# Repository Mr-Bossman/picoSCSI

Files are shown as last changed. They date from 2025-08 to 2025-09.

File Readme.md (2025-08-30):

# PicoSCSI

## A SD sard to Parallel SCSI hard drive emulator

### Board

The board design is lossely based on the [BlueSCSI V1](https://github.com/erichelgeson/BlueSCSI) and the [ZuluSCSI Pico](https://github.com/ZuluSCSI/ZuluSCSI-Pico-OSHW).
The [RP2350](https://www.raspberrypi.com/products/rp2350/) the MCU on the [Raspberry PI Pico 2](https://www.raspberrypi.com/products/raspberry-pi-pico-2/) is [5V tollerant](https://www.raspberrypi.com/news/rp2350-a4-rp2354-and-a-new-hacking-challenge/) meaning no level translation logic is nessasary.
Like BlueSCSI this outputs 3.3V to the bus, which is compliant with LV SCSI.

#### Documents relating to 5V tollerance
[Piers Finlayson's video](https://www.youtube.com/watch?v=Zy8IMe6fMI4&t=1768s) on the RP2350 variant of
[one-rom](https://github.com/piersfinlayson/one-rom/blob/main/sdrr-pcb/verified/rp2350-24-pin-rev-a/one-rom-24-pin-rp2350-rev-a-schematic.pdf) talks about caveats this may have.
The A4 silicon revision adds support for this https://www.raspberrypi.com/news/rp2350-a4-rp2354-and-a-new-hacking-challenge noted at the bottom.

### Firmware

Coming soon will be based on [ZuluSCSI firmware](https://github.com/ZuluSCSI/ZuluSCSI-firmware)

### TODO:

Add both SMD and THT versions
Add DB25 version
Fix Pi Pico not having combined THT and SMD footprint

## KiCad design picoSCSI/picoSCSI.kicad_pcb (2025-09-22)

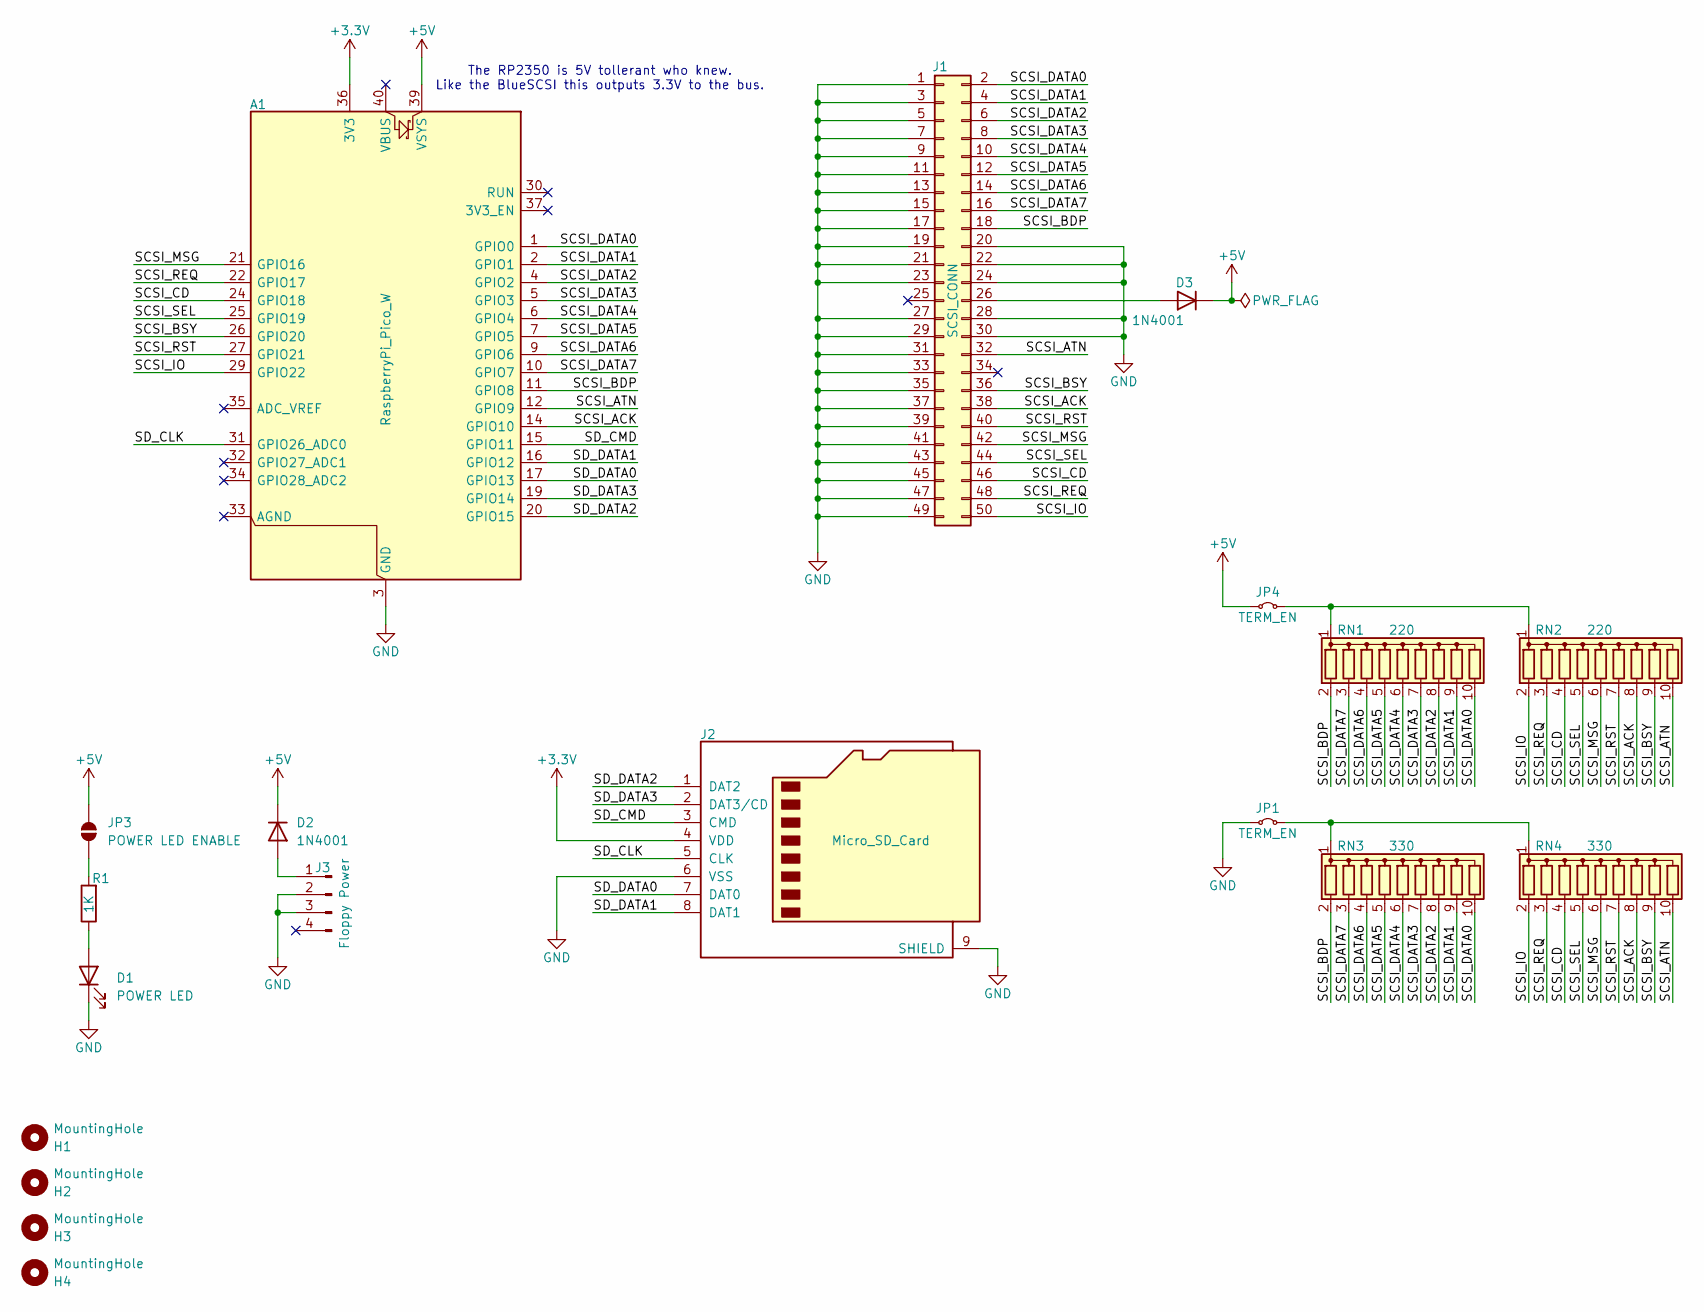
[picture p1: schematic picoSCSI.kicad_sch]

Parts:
A1: RaspberryPi_Pico_W; RaspberryPi_Pico_W_SMD_HandSolder
D1: POWER LED; LED_D5.0mm
D2, D3: 1N4001; D_DO-41_SOD81_P7.62mm_Horizontal
H1, H2, H3, H4: MountingHole; MountingHole_3.2mm_M3_ISO7380
J1: SCSI_CONN; IDC-Header_2x25_P2.54mm_Vertical
J2: Micro_SD_Card; microSD_HC_Wuerth_693072010801
J3: Floppy Power; JST_PH_B4B-PH-K_1x04_P2.00mm_Vertical
JP1, JP4: TERM_EN; PinSocket_1x02_P2.54mm_Vertical
JP3: POWER LED ENABLE; SolderJumper-2_P1.3mm_Open_RoundedPad1.0x1.5mm
R1: 1K; R_Axial_DIN0204_L3.6mm_D1.6mm_P5.08mm_Horizontal
RN1, RN2: 220; R_Array_SIP10
RN3, RN4: 330; R_Array_SIP10

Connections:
+3.3V: A1.36 (3V3), J2.4 (VDD)
+5V: A1.39 (VSYS), D2.1 (K), D3.1 (K), JP3.2 (B), JP4.1 (A)
/SCSI_ACK: A1.14 (GPIO10), J1.38, RN2.8 (R7), RN4.8 (R7)
/SCSI_ATN: A1.12 (GPIO9), J1.32, RN2.10 (R9), RN4.10 (R9)
/SCSI_BDP: A1.11 (GPIO8), J1.18, RN1.2 (R1), RN3.2 (R1)
/SCSI_BSY: A1.26 (GPIO20), J1.36, RN2.9 (R8), RN4.9 (R8)
/SCSI_CD: A1.24 (GPIO18), J1.46, RN2.4 (R3), RN4.4 (R3)
/SCSI_DATA0: A1.1 (GPIO0), J1.2, RN1.10 (R9), RN3.10 (R9)
/SCSI_DATA1: A1.2 (GPIO1), J1.4, RN1.9 (R8), RN3.9 (R8)
/SCSI_DATA2: A1.4 (GPIO2), J1.6, RN1.8 (R7), RN3.8 (R7)
/SCSI_DATA3: A1.5 (GPIO3), J1.8, RN1.7 (R6), RN3.7 (R6)
/SCSI_DATA4: A1.6 (GPIO4), J1.10, RN1.6 (R5), RN3.6 (R5)
/SCSI_DATA5: A1.7 (GPIO5), J1.12, RN1.5 (R4), RN3.5 (R4)
/SCSI_DATA6: A1.9 (GPIO6), J1.14, RN1.4 (R3), RN3.4 (R3)
/SCSI_DATA7: A1.10 (GPIO7), J1.16, RN1.3 (R2), RN3.3 (R2)
/SCSI_IO: A1.29 (GPIO22), J1.50, RN2.2 (R1), RN4.2 (R1)
/SCSI_MSG: A1.21 (GPIO16), J1.42, RN2.6 (R5), RN4.6 (R5)
/SCSI_REQ: A1.22 (GPIO17), J1.48, RN2.3 (R2), RN4.3 (R2)
/SCSI_RST: A1.27 (GPIO21), J1.40, RN2.7 (R6), RN4.7 (R6)
/SCSI_SEL: A1.25 (GPIO19), J1.44, RN2.5 (R4), RN4.5 (R4)
/SD_CLK: A1.31 (GPIO26_ADC0), J2.5 (CLK)
/SD_CMD: A1.15 (GPIO11), J2.3 (CMD)
/SD_DATA0: A1.17 (GPIO13), J2.7 (DAT0)
/SD_DATA1: A1.16 (GPIO12), J2.8 (DAT1)
/SD_DATA2: A1.20 (GPIO15), J2.1 (DAT2)
/SD_DATA3: A1.19 (GPIO14), J2.2 (DAT3/CD)
GND: A1.3 (GND), A1.8 (GND), A1.13 (GND), A1.18 (GND), A1.23 (GND), A1.28 (GND), A1.38 (GND), D1.1 (K), J1.1, J1.3, J1.5, J1.7, J1.9, J1.11, J1.13, J1.15, J1.17, J1.19, J1.20, J1.21, J1.22, J1.23, J1.24, J1.27, J1.28, J1.29, J1.30, J1.31, J1.33, J1.35, J1.37, J1.39, J1.41, J1.43, J1.45, J1.47, J1.49, J2.6 (VSS), J2.9 (SHIELD), J3.2, J3.3, JP1.1 (A)
unnamed: D1.2 (A), R1.1
unnamed: D2.2 (A), J3.1
unnamed: D3.2 (A), J1.26
unnamed: JP1.2 (B), RN3.1 (common), RN4.1 (common)
unnamed: JP3.1 (A), R1.2
unnamed: JP4.2 (B), RN1.1 (common), RN2.1 (common)

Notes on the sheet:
The RP2350 is 5V tollerant who knew. Like the BlueSCSI this outputs 3.3V to the bus.

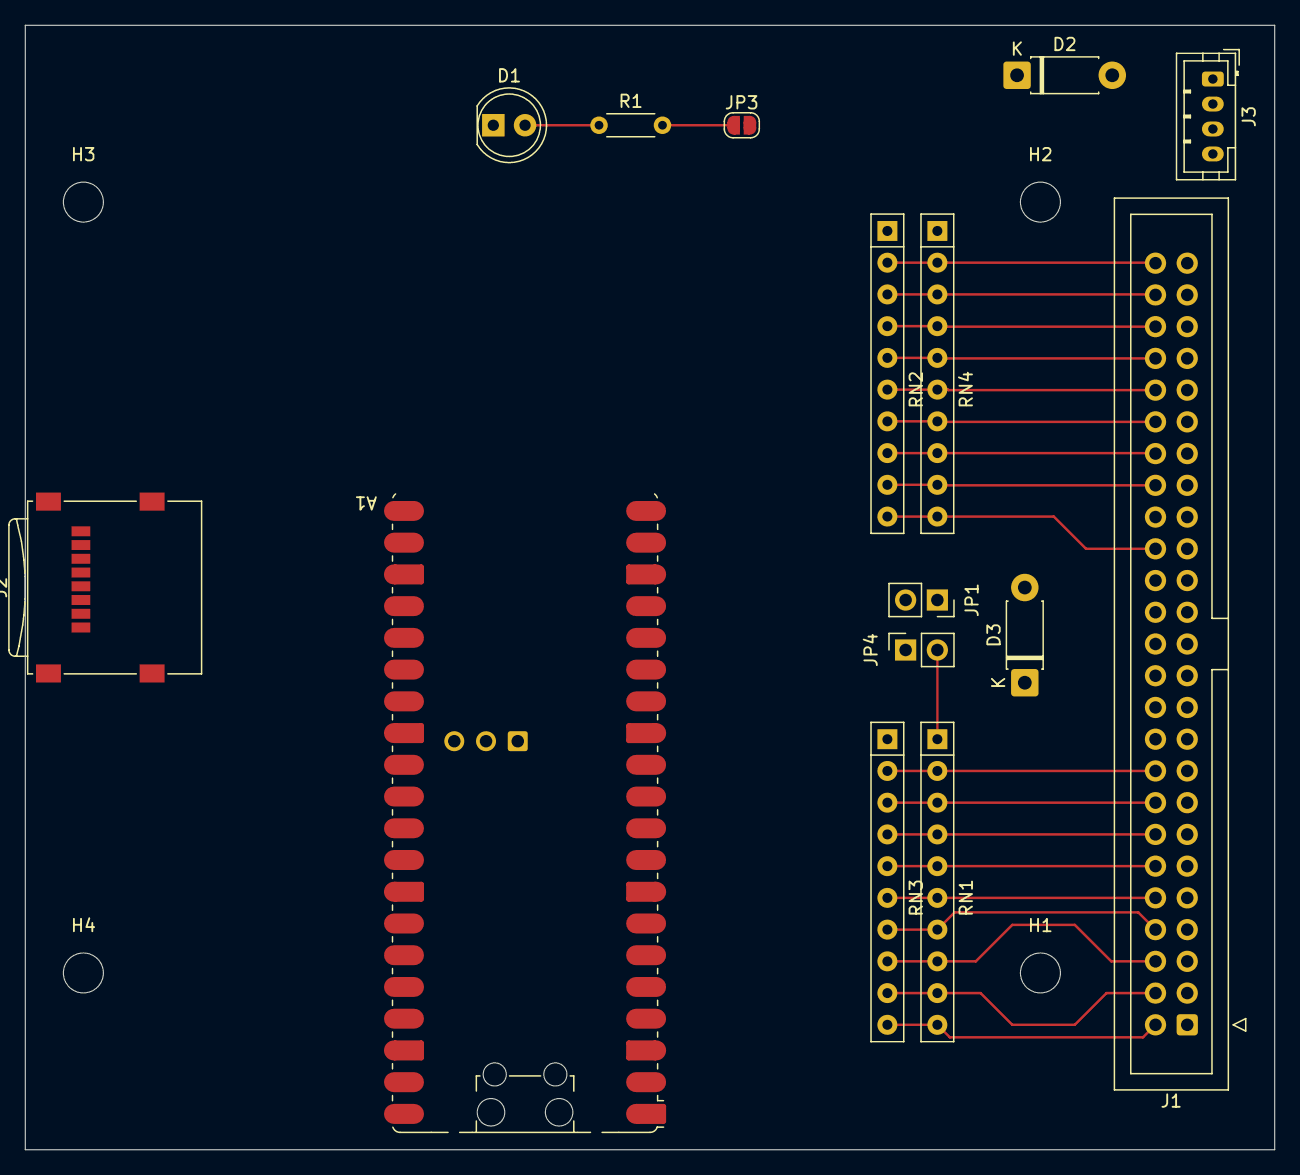
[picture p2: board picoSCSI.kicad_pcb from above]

Board: 2 copper layers, 100.0 x 90.0 mm, 19 parts (0 on the bottom side), 33 nets.
